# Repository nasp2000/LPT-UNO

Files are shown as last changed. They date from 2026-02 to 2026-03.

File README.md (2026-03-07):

# LPT-UNO — Parallel Port Printer Emulator


[]()
[]()
[]()

Turn an Arduino Uno into a **LPT/DB25 parallel port emulator**. Data received via the parallel interface is forwarded over USB Serial (or WiFi on R4) to a browser-based interface for real-time visualization and printing.

> No parallel printer required. Works with old DOS apps, legacy software, and educational setups.

<p align="center">
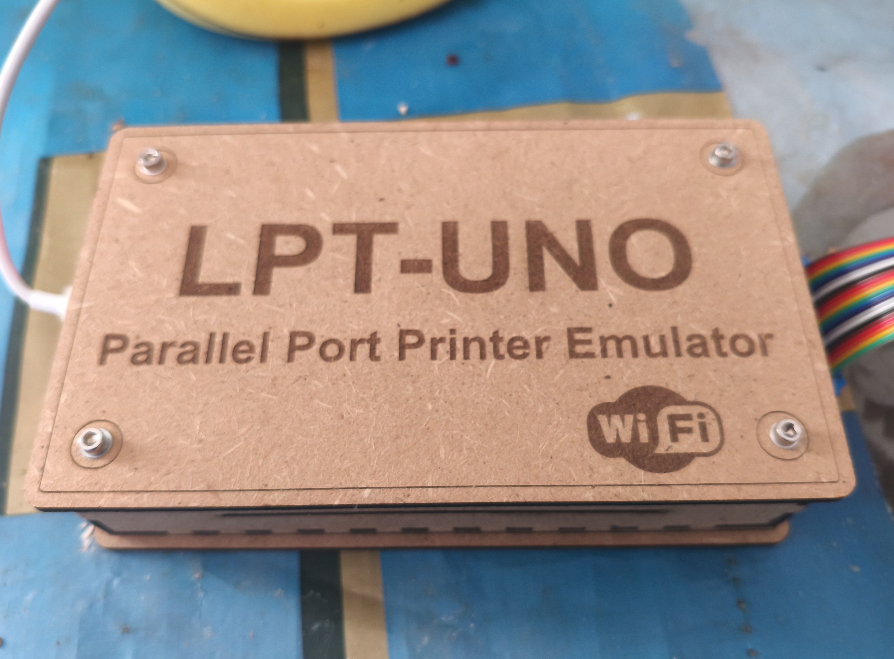
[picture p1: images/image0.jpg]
  
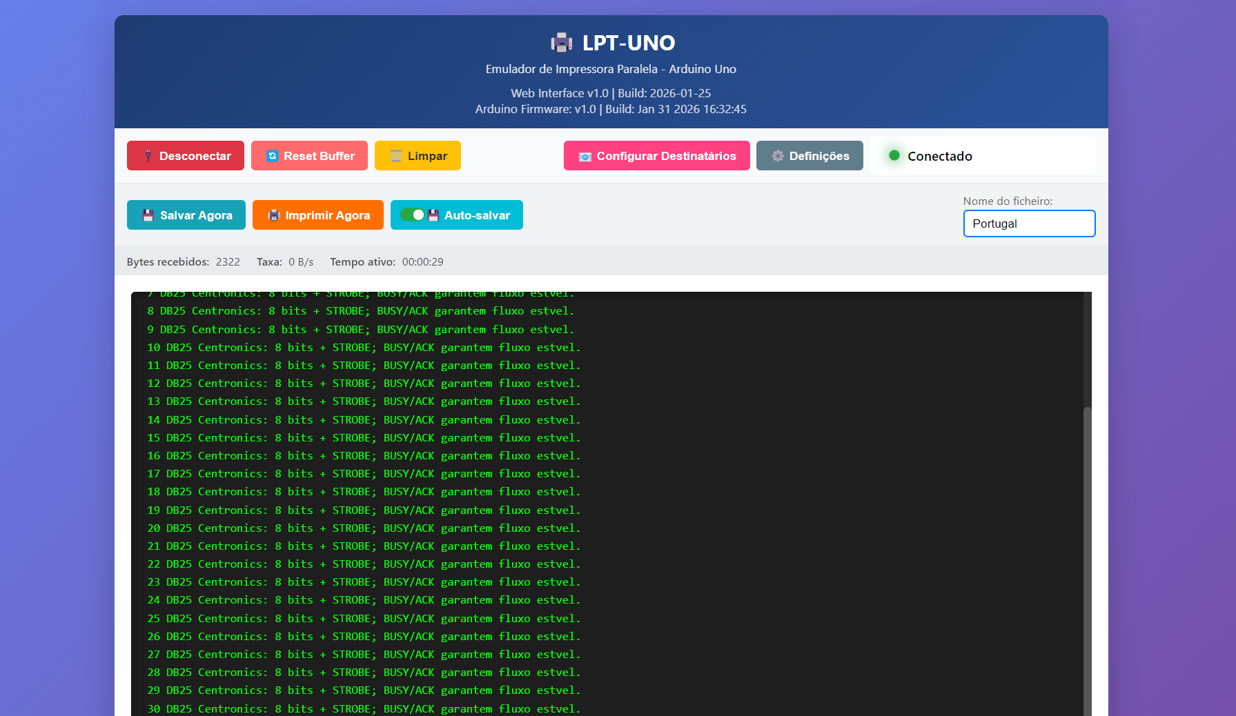
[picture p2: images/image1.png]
  
</p>
<p align="center">
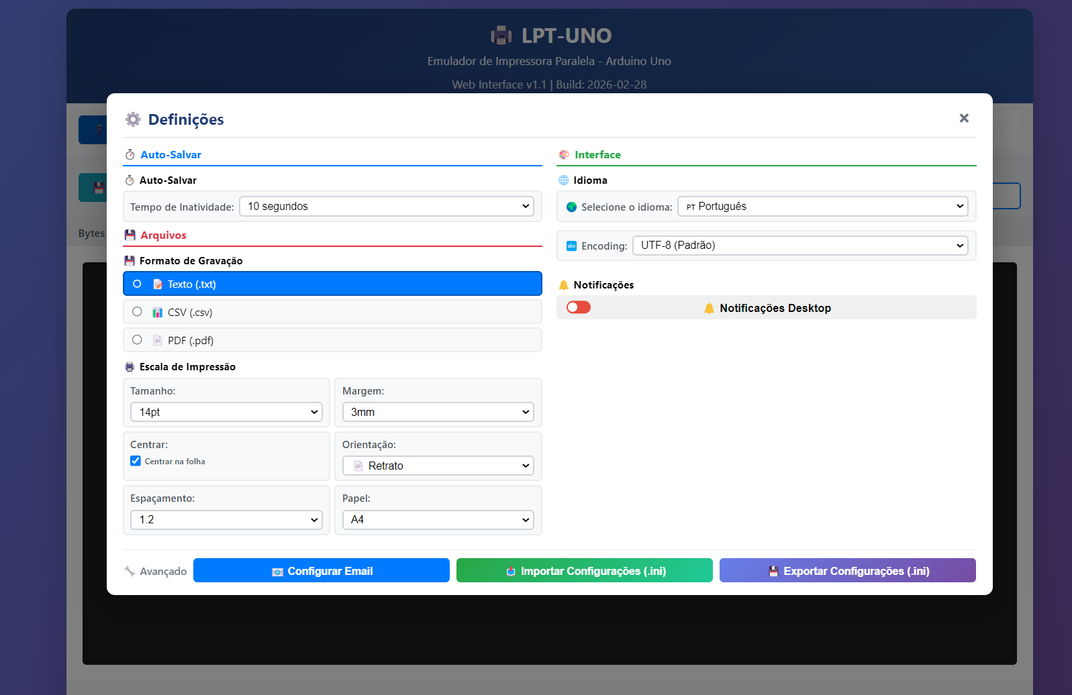
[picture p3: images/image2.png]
  
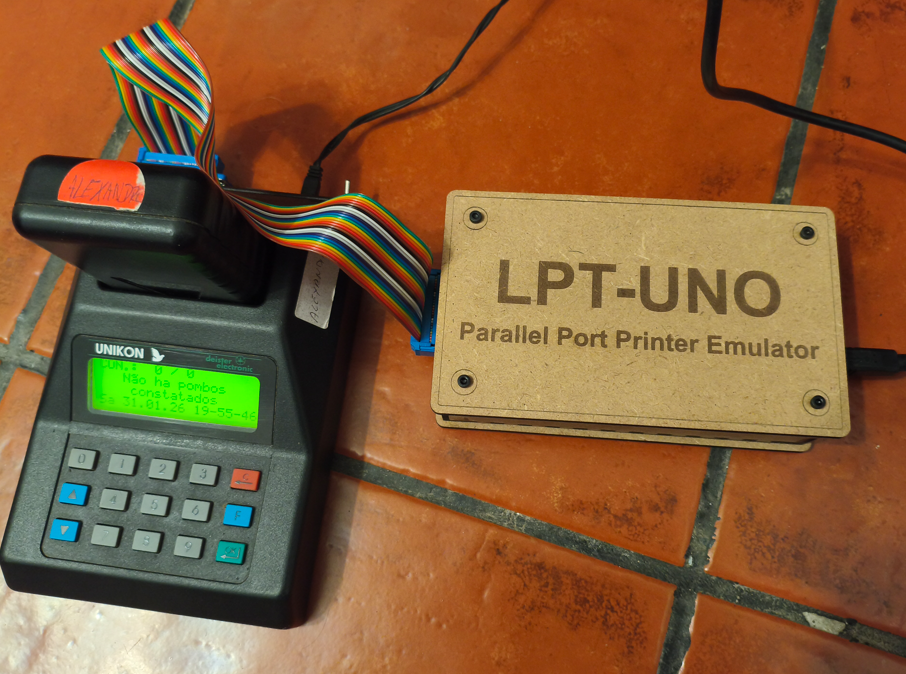
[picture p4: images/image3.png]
  
</p>

---

## Quick Start

1. Upload **LPT_Emulator/LPT_Emulator.ino** via Arduino IDE (115200 baud).
2. Open **web_interface.html** in Chrome or Edge.
3. Click **Connect** and select the Arduino COM port.

---

## Wiring (DB25 → Arduino)

| DB25 | Arduino | Signal |
|---|---|---|
| 1 | D2 | STROBE (INT0) |
| 2–9 | D3–D10 | D0–D7 (data) |
| 10 | D11 | ACK |
| 11 | D12 | BUSY |
| 13 | D13 | SELECT |
| 18–25 | GND | Ground |

> Use **5V TTL** levels only. See [PINOUT.txt](PINOUT.txt) for full diagram.

---

## Arduino Uno R4 WiFi

The R4 WiFi is fully supported with the same wiring. To use WiFi:

1. Upload the firmware to the Uno R4 WiFi.
2. Open **web_interface.html**, go to **Settings → WiFi** and enter your network credentials (SSID and password).
3. Click **Connect** — the interface discovers the board automatically or you can enter the IP manually.

| | Uno R3 | Uno R4 WiFi |
|---|---|---|
| CPU | ATmega328P 16 MHz | RA4M1 48 MHz |
| RAM | 2 KB | 32 KB |
| Connectivity | USB | USB + WiFi |

---

## Serial Commands

| Command | Action |
|---|---|
| `V` | Firmware version |
| `S` | Buffer usage |
| `R` | Reset buffer |
| `?` | Help |

---

## Troubleshooting

- **No connection:** check COM port, reset board, re-upload firmware.
- **No data:** verify STROBE is on pin D2, check wiring and GND.
- **Garbled text:** try CP‑437 encoding (DOS apps) in the web interface.
- **WiFi not found:** confirm credentials, check Serial Monitor for IP.

---

## License

MIT © 2026 LPT-UNO Project

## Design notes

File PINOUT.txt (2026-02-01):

╔════════════════════════════════════════════════════════════════╗
║      PINOUT - LPT PRINTER EMULATOR FOR ARDUINO UNO             ║
╚════════════════════════════════════════════════════════════════╝

┌─────────────────────────────────────────────────────────────────┐
│ DB25 CONNECTOR (FEMALE) - FRONT VIEW                           │
│                                                                 │
│     13  12  11  10   9   8   7   6   5   4   3   2   1        │
│    ○   ○   ○   ○   ○   ○   ○   ○   ○   ○   ○   ○   ○          │
│      ○   ○   ○   ○   ○   ○   ○   ○   ○   ○   ○   ○            │
│     25  24  23  22  21  20  19  18  17  16  15  14             │
└─────────────────────────────────────────────────────────────────┘

╔════════════════════════════════════════════════════════════════╗
║                    CONNECTION TABLE                            ║
╠════════╦═══════════╦═════════════╦═══════╦═════════════════════╣
║ DB25   ║  SIGNAL   ║  ARDUINO    ║ TYPE  ║  DESCRIPTION        ║
╠════════╬═══════════╬═════════════╬═══════╬═════════════════════╣
║   1    ║  STROBE   ║  Digital 2  ║  IN   ║ Data ready (INT0) ⚡║
║   2    ║  D0       ║  Digital 3  ║  IN   ║ Data bit 0          ║
║   3    ║  D1       ║  Digital 4  ║  IN   ║ Data bit 1          ║
║   4    ║  D2       ║  Digital 5  ║  IN   ║ Data bit 2          ║
║   5    ║  D3       ║  Digital 6  ║  IN   ║ Data bit 3          ║
║   6    ║  D4       ║  Digital 7  ║  IN   ║ Data bit 4          ║
║   7    ║  D5       ║  Digital 8  ║  IN   ║ Data bit 5          ║
║   8    ║  D6       ║  Digital 9  ║  IN   ║ Data bit 6          ║
║   9    ║  D7       ║  Digital 10 ║  IN   ║ Data bit 7          ║
║  10    ║  ACK      ║  Digital 11 ║  OUT  ║ Acknowledge         ║
║  11    ║  BUSY     ║  Digital 12 ║  OUT  ║ Busy                ║
║  12    ║  PAPER    ║  (not used) ║   -   ║ Paper out           ║
║  13    ║  SELECT   ║  Digital 13 ║  OUT  ║ Selected            ║
║  14    ║  AUTOFEED ║  (not used) ║   -   ║ Auto feed           ║
║  15    ║  ERROR    ║  (not used) ║   -   ║ Error               ║
║  16    ║  INIT     ║  (not used) ║   -   ║ Initialize          ║
║  17    ║  SELECT IN║  (not used) ║   -   ║ Select input        ║
║ 18-25  ║  GND      ║  GND        ║   -   ║ Ground              ║
╚════════╩═══════════╩═════════════╩═══════╩═════════════════════╝

╔════════════════════════════════════════════════════════════════╗
║                 ARDUINO WIRING DIAGRAM                         ║
╠════════════════════════════════════════════════════════════════╣
║                                                                ║
║   DB25 Pin 1  (STROBE) ──────────► Arduino D2  (INT0) ⚡       ║
║   DB25 Pin 2  (D0)     ──────────► Arduino D3                 ║
║   DB25 Pin 3  (D1)     ──────────► Arduino D4                 ║
║   DB25 Pin 4  (D2)     ──────────► Arduino D5                 ║
║   DB25 Pin 5  (D3)     ──────────► Arduino D6                 ║
║   DB25 Pin 6  (D4)     ──────────► Arduino D7                 ║
║   DB25 Pin 7  (D5)     ──────────► Arduino D8                 ║
║   DB25 Pin 8  (D6)     ──────────► Arduino D9                 ║
║   DB25 Pin 9  (D7)     ──────────► Arduino D10                ║
║   DB25 Pin 10 (ACK)    ◄────────── Arduino D11                ║
║   DB25 Pin 11 (BUSY)   ◄────────── Arduino D12                ║
║   DB25 Pin 13 (SELECT) ◄────────── Arduino D13 (LED)          ║
║   DB25 Pin 18-25 (GND) ──────────► Arduino GND                ║
║                                                                ║
║   Arduino USB ───────────────────► PC (Serial 115200 baud)    ║
╚════════════════════════════════════════════════════════════════╝

╔════════════════════════════════════════════════════════════════╗
║                  ⚠️  CRITICAL WARNING ⚠️                        ║
╠════════════════════════════════════════════════════════════════╣
║  STROBE MUST BE CONNECTED TO PIN 2 (INT0)!                    ║
║                                                                ║
║  Arduino Uno only has hardware interrupts on:                 ║
║  - Pin 2 (INT0)  ← Use this for STROBE                        ║
║  - Pin 3 (INT1)                                               ║
║                                                                ║
║  The emulator will NOT work if STROBE is on any other pin!    ║
╚════════════════════════════════════════════════════════════════╝

╔════════════════════════════════════════════════════════════════╗
║                    LOGIC LEVELS                                ║
╠════════════════════════════════════════════════════════════════╣
║  HIGH = 5V (logic 1)                                           ║
║  LOW  = 0V (logic 0)                                           ║
║                                                                ║
║  STROBE: Active LOW (low pulse indicates data ready)          ║
║  ACK:    Active LOW (low pulse = acknowledgment)              ║
║  BUSY:   Active HIGH (high level = busy)                      ║
║  SELECT: Active HIGH (high level = ready)                     ║
╚════════════════════════════════════════════════════════════════╝

╔════════════════════════════════════════════════════════════════╗
║                  PROTOCOL TIMING                               ║
╠════════════════════════════════════════════════════════════════╣
║                                                                ║
║  1. PC places data on D0-D7                                   ║
║  2. PC activates STROBE (HIGH → LOW)  ───┐                    ║
║  3. Arduino detects STROBE                │ < 2 µs (interrupt)║
║  4. Arduino activates BUSY (LOW → HIGH) ──┘                   ║
║  5. Arduino reads data                    ──┐                 ║
║  6. Arduino stores in buffer                │ ~10 µs          ║
║  7. Arduino sends ACK (LOW pulse)           │                 ║
║  8. Arduino deactivates BUSY (HIGH → LOW)───┘                 ║
║                                                                ║
║  ACK pulse width:   ~5 microseconds                           ║
║  BUSY time:         ~10 microseconds                          ║
║  Maximum rate:      ~100 kB/s (theoretical)                   ║
╚════════════════════════════════════════════════════════════════╝

╔════════════════════════════════════════════════════════════════╗
║                   IMPORTANT NOTES                              ║
╠════════════════════════════════════════════════════════════════╣
║                                                                ║
║  • Use short cables (< 2 meters) to avoid noise              ║
║  • Connect ALL GND pins (18-25) to Arduino GND               ║
║  • Arduino Uno uses 5V TTL levels (compatible with LPT)      ║
║  • Pin D2 has hardware interrupt (INT0) (essential for STROBE)  ║
║  • Pin D13 has onboard LED (useful for debugging)            ║
║  • Serial rate: 115200 baud (maximum speed)                  ║
║  • Buffer: 256 bytes circular                                 ║
║                                                                ║
╚════════════════════════════════════════════════════════════════╝

╔════════════════════════════════════════════════════════════════╗
║                  REQUIRED MATERIALS                            ║
╠════════════════════════════════════════════════════════════════╣
║                                                                ║
║  [ ] 1x Arduino Uno R3                                        ║
║  [ ] 1x DB25 female connector                                 ║
║  [ ] 1x USB cable type A-B                                    ║
║  [ ] 13x Jumper wires male-male (data + control)             ║
║  [ ] 1x Jumper wire for GND                                   ║
║  [ ] 1x Breadboard (optional, for organization)              ║
║  [ ] 1x Soldering iron + solder (if soldering DB25)          ║
║                                                                ║
╚════════════════════════════════════════════════════════════════╝

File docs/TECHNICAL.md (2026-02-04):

# Technical Reference — LPT-UNO

## Important Notes

- **STROBE must be on Arduino Pin 2 (INT0)**: Arduino Uno only has hardware interrupts on pins 2 and 3 (INT0/INT1). The STROBE signal MUST be connected to pin 2 (INT0) for the emulator to work.
- **Voltage levels**: Parallel ports use 5V TTL logic (Arduino Uno compatible).
- **Do NOT use** 3.3V Arduinos without proper level shifting.
- **Cable length**: Prefer cables < 2 meters to avoid noise and data corruption.
- **Ground connection**: Connect all DB25 ground pins (18-25) to Arduino GND.

---

## Software Installation

### Step 1: Upload Arduino Firmware

1. Download or clone this repository
2. Open `LPT_Emulator/LPT_Emulator.ino` in Arduino IDE
3. Tools → Board → Arduino Uno
4. Tools → Port → [Your COM Port]
5. Upload (Ctrl+U)

### Step 2: Test the Connection

Open Arduino Serial Monitor (115200 baud):
- `V` - show firmware version
- `S` - show statistics
- `R` - reset buffer
- `?` - help

### Step 3: Launch Native App

- Windows (recommended): build and run the `LPTUnoApp` application (see `LPTUnoApp/README.md`) to open the native interface and enable auto-print/move monitor.
- The legacy `web_interface.html` has been removed in this branch; use the native app for connection and printing.

---

## Web Interface Details

- **Encodings**: UTF-8 (default), ISO-8859-1 (Latin), CP-437 (DOS), Windows-1252. For CP-437 the UI uses a conversion table; other encodings use TextDecoder.
- **Auto-save**: configurable inactivity timer (default 10s).
- **Auto-print**: controlled by the native app (AutoPrint flag and Move Monitor). Files are moved from Downloads to `DATA` and printed by the app's `MoveManager` / `PrintManager` components (replacing `LPT-UNO_MoveToData.ps1`).

---

## Communication & Timing (IEEE 1284 compatibility)

1. PC places data on D0-D7 pins
2. PC toggles STROBE (HIGH → LOW transition)
3. Arduino detects STROBE via hardware interrupt
4. Arduino sets BUSY while processing
5. Arduino reads D0-D7 and stores the byte in a 256-byte circular buffer
6. Arduino pulses ACK (~5 μs low)
7. Arduino clears BUSY and forwards data via USB Serial in the main loop

**Timing specs:**
- STROBE detection: < 2 μs
- BUSY activation: ~10 μs
- ACK pulse: ~5 μs
- Max theoretical throughput: ~100 kB/s
- Serial baud rate: 115200

---

## Serial Commands

Type commands at 115200 baud in the Serial Monitor:

| Command | Action |
|---|---|
| `V` / `v` | Show firmware version and build date |
| `S` / `s` | Show statistics (buffer usage) |
| `R` / `r` | Reset buffer |
| `?` | Help |

Example:
```
> V
Firmware Version: 1.0
Build Date: Jan 25 2026 14:30:00

> S
Buffer usage: 42/256 bytes
```

---

## Pinout & Wiring

See `PINOUT.txt` for a complete ASCII diagram. Key mappings:
- STROBE: DB25 pin 1 → Arduino D2
- D0..D7: DB25 pins 2..9 → Arduino D3..D10
- ACK: DB25 pin 10 → Arduino D11
- BUSY: DB25 pin 11 → Arduino D12
- SELECT: DB25 pin 13 → Arduino D13
- GND: DB25 pins 18..25 → Arduino GND

---

## Debugging Tips

- If no data: confirm wiring and STROBE pin; test with Arduino Serial Monitor first.
- If characters are garbled: try CP-437 (DOS) or ISO-8859-1 in the UI; verify encoding of the source data.
- If auto-print doesn't run: ensure `.autoprint_enabled` exists in `DATA` and the native app's Move Monitor is running (see `LPTUnoApp` MoveManager).

---

(End of technical reference)

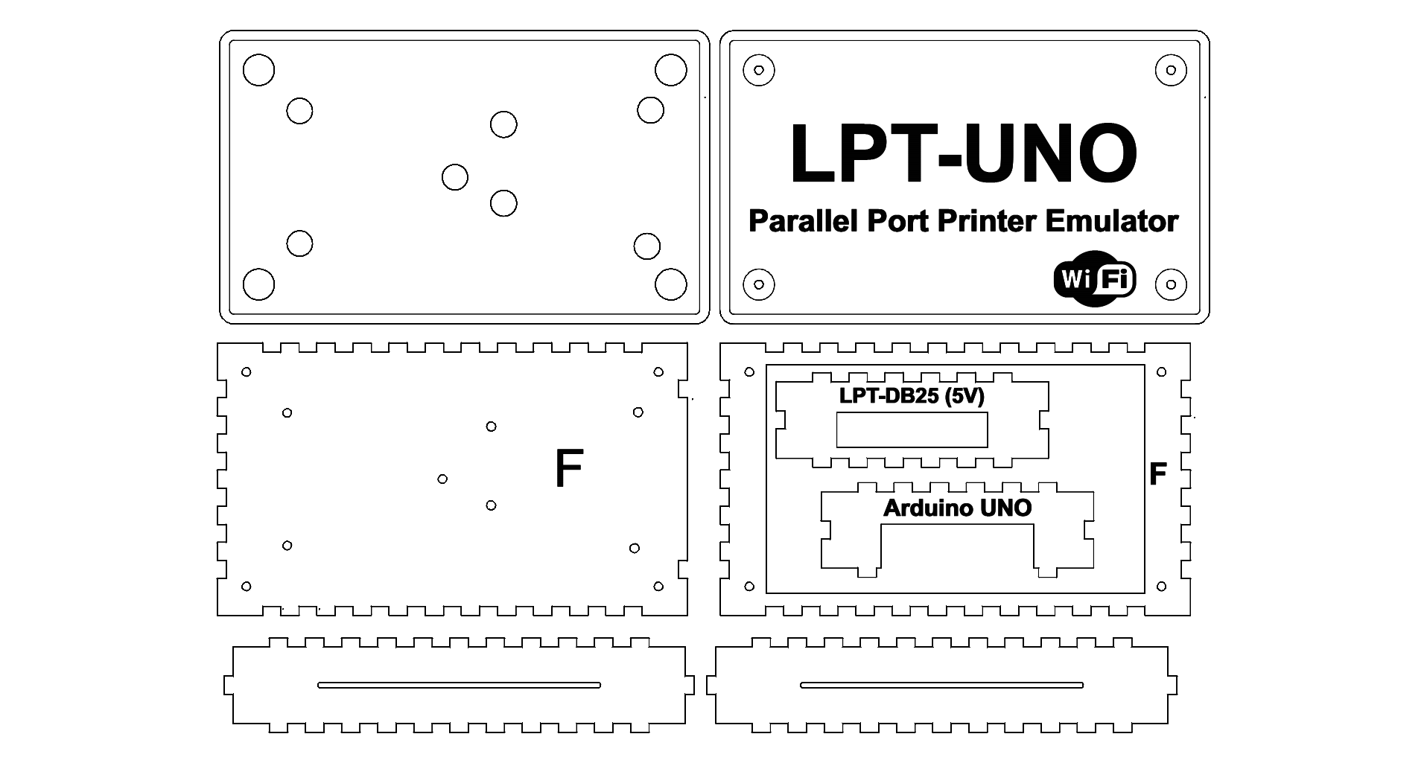
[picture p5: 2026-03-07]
images/drawings.png

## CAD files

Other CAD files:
images/drawings.dxf

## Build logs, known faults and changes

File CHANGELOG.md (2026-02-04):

# Changelog

All notable changes to the LPT-UNO project will be documented in this file.

The format is based on [Keep a Changelog](https://keepachangelog.com/en/1.0.0/),
and this project adheres to [Semantic Versioning](https://semver.org/spec/v2.0.0.html).

## [1.0] - 2026-01-31

### Added
- Initial release of LPT-UNO Parallel Port Printer Emulator
- Arduino Uno firmware with IEEE 1284 compatibility mode
- Web-based interface with Web Serial API support
- Auto-save feature (saves data every 10 seconds)
- Multi-language support (English, Portuguese, Spanish)
- Serial commands for monitoring and debugging (V, S, R, ?)
- 256-byte circular buffer for reliable data handling
- Hardware interrupt support for fast response (<2µs)
- Real-time data visualization in browser
- Manual save as TXT file
- Connection status indicators
- Firmware version display
- Buffer statistics monitoring
- **Controle de auto-print via Ativar_AutoPrint.bat e Desativar_AutoPrint.bat**
- **Automatic printing via LPT-UNO_MoveToData.ps1 (PowerShell)**
- **Launcher LPT-UNO_AutoPrint_Direct.bat para fluxo completo**

### Hardware
- Full pinout for DB25 to Arduino Uno
- Support for 8-bit parallel data (D0-D7)
- Control signals: STROBE, ACK, BUSY, SELECT
- Interrupt-driven STROBE detection on pin 2 (INT0)
- LED indicator on pin 13 (SELECT signal)

### Documentation
- Comprehensive README in English
- Detailed pinout diagram (PINOUT.txt)
- Wiring instructions and connection guide
- Troubleshooting section
- Technical specifications
- Development guidelines

### Files
- `LPT_Emulator/LPT_Emulator.ino` - Arduino firmware v1.0
- `LPTUnoApp/` - Native Windows app prototype (branch `LPT-UNO-Wifi`)
- `PINOUT.txt` - ASCII art pinout diagram
- `README.md` - Complete documentation
- `LICENSE` - MIT License
- `.gitignore` - Git ignore rules
- `.github/copilot-instructions.md` - Coding guidelines

---

## [Unreleased]

### Added
- Native Windows prototype app (WPF) in branch `LPT-UNO-Wifi` — initial prototype: tray app, config file, data folder and basic UI.
- AutoPrint watcher and PrintManager (monitor DATA folder and print `*.txt` files automatically). 
- Basic serial reconnection logic (periodic reconnection attempts to saved COM port).
- MoveToData functionality: monitor `Downloads` and move timestamped files into `DATA` (replaces `LPT-UNO_MoveToData.ps1`).
- Added controls to create/remove `.autoprint_enabled` flag and to start/stop Downloads monitor (replacing `Ativar/Desativar_AutoPrint.bat` behaviors).
- Added installer packaging scripts and an Inno Setup definition for Windows installer (`installer/`).

### Removed
- `web_interface.html` — Legacy web interface removed in favor of the native app (branch `LPT-UNO-Wifi`).
- Legacy helper scripts removed: `Ativar_AutoPrint.bat`, `Desativar_AutoPrint.bat`, `LPT-UNO_AutoPrint_Direct.bat`, `LPT-UNO_MoveToData.ps1` (functionality replaced by MoveManager/PrintManager).

### Fixed
- Discovery: Handle IPv6 addresses and bracketed `[IPv6]:port` notation to allow auto-connect on IPv6 networks.
- Tray icon: Properly destroy native icon handle on exit to avoid resource leak.

### Added
- Minimize-to-tray preference (persisted in config) with UI checkbox `ChkMinimizeToTray`.
- Runtime creation of a placeholder `images/printer.png` when missing and automatic generation of `TrayIcon.ico` so the app always shows a tray icon.
- Programmatically generate a simple printer icon (32×32) when no custom icon is supplied.

### Future Ideas
- Support for other Arduino boards (Mega, Due, ESP32)
- Bidirectional communication (EPP/ECP modes)
- Mobile-friendly responsive interface
- Linux/macOS launcher scripts
- Advanced printer emulation features
- Configuration file support
- Data filtering and formatting options
- Multiple buffer size options
- Advanced timing adjustment
- Built-in data logger
- Network printing support
- Virtual printer driver

---

## Version Numbering

- **Major (X.0.0)**: Breaking changes, major new features, architectural changes
- **Minor (1.X.0)**: New features, improvements, significant bug fixes
- **Patch (1.0.X)**: Small bug fixes, documentation updates (optional)

---

*For a complete list of changes, see the [commit history](https://github.com/yourusername/LPT-UNO/commits).*

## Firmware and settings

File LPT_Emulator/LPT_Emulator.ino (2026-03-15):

/*
 * Emulador de Impressora Paralela LPT (DB25) para Arduino Uno
 * LPT-UNO Firmware
 * 
 * Este código transforma o Arduino Uno num emulador de impressora paralela
 * que recebe dados pela interface paralela e os envia via USB Serial para o PC.
 * 
 * PINAGEM DO ARDUINO UNO:
 * ========================
 * Sinais de Controle:
 *   STROBE (DB25 pino 1)   -> Arduino Digital 2 (INT0 - Interrupt)
 *   ACK    (DB25 pino 10)  -> Arduino Digital 11 (Output)
 *   BUSY   (DB25 pino 11)  -> Arduino Digital 12 (Output)
 *   SELECT (DB25 pino 13)  -> Arduino Digital 13 (Output + LED)
 * 
 * Dados Paralelos (8 bits):
 *   D0 (DB25 pino 2)  -> Arduino Digital 3
 *   D1 (DB25 pino 3)  -> Arduino Digital 4
 *   D2 (DB25 pino 4)  -> Arduino Digital 5
 *   D3 (DB25 pino 5)  -> Arduino Digital 6
 *   D4 (DB25 pino 6)  -> Arduino Digital 7
 *   D5 (DB25 pino 7)  -> Arduino Digital 8
 *   D6 (DB25 pino 8)  -> Arduino Digital 9
 *   D7 (DB25 pino 9)  -> Arduino Digital 10
 * 
 * GND: DB25 pinos 18-25 -> Arduino GND
 * 
 * PROTOCOLO:
 * 1. PC coloca dados nos pinos D0-D7
 * 2. PC ativa STROBE (nível baixo)
 * 3. Arduino lê os dados
 * 4. Arduino ativa BUSY (nível alto)
 * 5. Arduino processa/envia dados via USB Serial
 * 6. Arduino ativa ACK (pulso baixo)
 * 7. Arduino desativa BUSY (nível baixo)
 */

// ===========================
// INFORMAÇÕES DE VERSÃO
// ===========================
#define FIRMWARE_VERSION "1.1"
#define BUILD_DATE __DATE__
#define BUILD_TIME __TIME__

// ===========================
// WIFI SUPPORT (UNO R4 WIFI)
// ===========================
#if defined(ARDUINO_UNOR4_WIFI)
#include "WiFiS3.h"
#include <EEPROM.h>
#include <WiFiUdp.h>
#include <ArduinoMDNS.h>

// Credentials storage
struct Config {
  char ssid[33];
  char pass[64];
  byte valid;  // 0xAA indicates valid config
} wifiConfig;

int status = WL_IDLE_STATUS;
bool wifiConnected = false;

// HTTP server para web interface via streaming bruto (porta 80)
WiFiServer webServer(80);
WiFiClient streamClient;
bool streamClientConnected = false;

// Discovery
WiFiUDP udp;
unsigned long lastBroadcast = 0;

// mDNS — acessível como lpt-uno.local
WiFiUDP mdnsUdp;
MDNS mdns(mdnsUdp);

// Reconexão automática WiFi (state machine não-bloqueante)
unsigned long lastWifiCheck    = 0;
bool          wifiAttempting   = false;
unsigned long wifiAttemptStart = 0;
const unsigned long WIFI_CONNECT_ATTEMPT_TIMEOUT_MS = 12000UL;
const unsigned long WIFI_RETRY_INTERVAL_MS          = 3000UL;
bool          _wifiServicesStarted = false;   // impede webServer/udp.begin() repetido
unsigned long _lastKeepaliveMs     = 0;       // keepalive TCP no stream (0x00 a cada 5s)
#endif

// Buffer de receção de comandos Serial (não-bloqueante)
String serialCmdBuffer = "";

#if defined(ARDUINO_UNOR4_WIFI)
void loadConfig() {
  EEPROM.get(0, wifiConfig);
}

void saveConfig(String s, String p) {
  memset(wifiConfig.ssid, 0, 33);
  memset(wifiConfig.pass, 0, 64);
  s.toCharArray(wifiConfig.ssid, 33);
  p.toCharArray(wifiConfig.pass, 64);
  wifiConfig.valid = 0xAA;
  EEPROM.put(0, wifiConfig);
}

void startWifiConnectAttempt() {
  WiFi.disconnect();
  delay(60);
  WiFi.begin(wifiConfig.ssid, wifiConfig.pass);
  wifiAttempting   = true;
  wifiAttemptStart = millis();
}

// Buffer de stream HTTP bruto — sem overhead SSE/texto.
// O browser lê bytes raw com fetch().body.getReader(), o que é muito mais leve.
#define STREAM_BUF_CAP 2048
#define STREAM_FLUSH_THRESHOLD ((STREAM_BUF_CAP * 3) / 4)  // flush preventivo a ~75%
static uint8_t _streamBuf[STREAM_BUF_CAP];
static int     _streamBufLen = 0;
unsigned long  lastStreamFlush = 0;

void sendStreamData(byte b) {
  if (!streamClientConnected || !streamClient.connected()) {
    streamClientConnected = false;
    _streamBufLen = 0;
    return;
  }
  if (_streamBufLen >= STREAM_BUF_CAP - 1) flushStream();
  if (_streamBufLen < STREAM_BUF_CAP) {
    _streamBuf[_streamBufLen++] = b;
  }
  if (_streamBufLen >= STREAM_FLUSH_THRESHOLD) flushStream();
}

void flushStream() {
  if (_streamBufLen == 0 || !streamClientConnected || !streamClient.connected()) {
    if (_streamBufLen > 0) _streamBufLen = 0;
    return;
  }
  streamClient.write(_streamBuf, _streamBufLen);
  _streamBufLen = 0;
  lastStreamFlush = millis();
}

// ── Estado do cliente HTTP pendente ─────────────────────────────────────────
// O request é acumulado ao longo de várias iterações do loop (não-bloqueante).
// Resolve o problema anterior: timeout de 5µs/5ms era insuficiente para o
// WiFiS3 entregar os headers completos → GET /events nunca era reconhecido
// → EventSource fechava imediatamente → ciclo de retry infinito.
WiFiClient    _httpClient;
String        _httpReq     = "";
unsigned long _httpReqT    = 0;
bool          _httpPending = false;

bool _httpHasRequestLine(const String& req) {
  return req.indexOf("\r\n") >= 0 || req.indexOf('\n') >= 0;
}

bool _httpIsRecognizedPath(const String& req) {
  return req.indexOf("GET /ping") >= 0
      || req.indexOf("GET /stream") >= 0
      || req.indexOf("GET /status") >= 0
      || req.indexOf("GET /ip") >= 0;
}

// Despacha o request HTTP completo (ou com timeout)
void _dispatchHttp(WiFiClient& c, const String& req) {
  if (req.indexOf("GET /ping") >= 0) {
    c.println("HTTP/1.1 200 OK");
    c.println("Content-Type: application/json");
    c.println("Access-Control-Allow-Origin: *");
    c.println("Connection: close");
    c.println();
    IPAddress ip = WiFi.localIP();
    c.print("{\"d\":\"LPT-UNO\",\"ip\":\"");
    c.print(ip);
    c.print("\"}");
    c.stop();
  } else if (req.indexOf("GET /stream") >= 0) {
    c.println("HTTP/1.1 200 OK");
    c.println("Content-Type: application/octet-stream");
    c.println("Cache-Control: no-cache");
    c.println("Access-Control-Allow-Origin: *");
    c.println("Connection: keep-alive");
    c.println();
    c.flush();  // forçar envio imediato dos headers ao browser
    if (streamClient && streamClient.connected()) streamClient.stop();
    streamClient = c;
    streamClientConnected = true;
  } else if (req.indexOf("GET /status") >= 0 || req.indexOf("GET /ip") >= 0) {
    IPAddress ip = WiFi.localIP();
    String s = "{\"version\":\"" + String(FIRMWARE_VERSION) + "\",\"ip\":\""
               + String(ip[0])+"."+String(ip[1])+"."+String(ip[2])+"."+String(ip[3]) + "\"}";
    c.println("HTTP/1.1 200 OK");
    c.println("Content-Type: application/json");
    c.println("Access-Control-Allow-Origin: *");
    c.println("Connection: close");
    c.println();
    c.print(s);
    c.stop();
  } else {
    c.println("HTTP/1.1 200 OK");
    c.println("Content-Type: text/plain");
    c.println("Access-Control-Allow-Origin: *");
    c.println("Connection: close");
    c.println();
    IPAddress ip = WiFi.localIP();
    c.print("LPT-UNO v"); c.println(FIRMWARE_VERSION);
    c.print("STREAM: http://"); c.print(ip); c.println("/stream");
    c.stop();
  }
}

// Trata ligações HTTP — completamente não-bloqueante.
// IMPORTANTE: não aceita novas ligações enquanto stream activo — o WiFiS3
// devolve o próprio socket stream em webServer.available(), o que levaria
// o código a tratá-lo como novo pedido e após 500ms chamar c.stop(),
// matando a ligação HTTP streaming.
void handleWebClient() {
  // Enquanto stream activo e saudável: não aceitar novas ligações
  if (streamClientConnected) {
    if (!streamClient.connected()) {
      streamClientConnected = false;
      _streamBufLen = 0;
      _httpPending = false;
    }
    return;
  }

  // Aceitar novo cliente apenas se não há pedido em curso
  if (!_httpPending) {
    WiFiClient nc = webServer.available();
    if (!nc) return;
    _httpClient  = nc;
    _httpReq     = "";
    _httpReqT    = millis();
    _httpPending = true;
  }

  // Ler apenas o que já está no buffer (nunca esperar)
  while (_httpPending && _httpClient.connected()
         && _httpClient.available() && _httpReq.length() < 1024) {
    _httpReq += (char)_httpClient.read();
    if (_httpReq.endsWith("\r\n\r\n") || (_httpHasRequestLine(_httpReq) && _httpIsRecognizedPath(_httpReq))) {
      _httpPending = false;
      _dispatchHttp(_httpClient, _httpReq);
      return;
    }
  }

  // Timeout 500ms ou cliente desligou: despachar com o que foi recebido
  if (_httpPending && (!_httpClient.connected() || millis() - _httpReqT > 500UL)) {
    _httpPending = false;
    _dispatchHttp(_httpClient, _httpReq);
  }
}
#endif

// ===========================
// DEFINIÇÃO DE PINOS
// ===========================

// Pinos de controle (Input do PC)
const int PIN_STROBE = 2;  // Sinal de dados prontos (active low) - INT0

// Pinos de dados (D0-D7)
const int DATA_PINS[] = { 3, 4, 5, 6, 7, 8, 9, 10 };
const int DATA_PIN_COUNT = 8;

// Pinos de status (Output para o PC)
const int PIN_ACK = 11;     // Acknowledge (active low pulse)
const int PIN_BUSY = 12;    // Impressora ocupada (active high)
const int PIN_SELECT = 13;  // Impressora selecionada (active high)

// ===========================
// CONFIGURAÇÃO DE TIMING
// ===========================
// ACK mínimo IEEE 1284 = 0.5µs; 2µs é suficiente e seguro
// BUSY_DELAY = tempo de processamento simulado antes do ACK
// Ambos reduzidos para 2µs: ISR total ~4-6µs → suporta até HIPER_RAPIDO (gap=10µs)
// Profile de velocidades (teste):
//   LENTO:        dataSettle=10µs  strobe=50µs  gap=200µs  ✓
//   NORMAL:       dataSettle= 5µs  strobe=20µs  gap=100µs  ✓
//   RAPIDO:       dataSettle= 2µs  strobe= 8µs  gap= 30µs  ✓
//   SUPER_RAPIDO: dataSettle= 1µs  strobe= 5µs  gap= 15µs  ✓
//   HIPER_RAPIDO: dataSettle= 1µs  strobe= 3µs  gap= 10µs  ✓
const unsigned long ACK_PULSE_MICROS = 2;    // Pulso ACK: 2µs (mínimo seguro)
const unsigned long BUSY_DELAY_MICROS = 2;   // Processamento: 2µs

// ===========================
// BUFFER DE DADOS
// ===========================
#if defined(ARDUINO_UNOR4_WIFI)
const int BUFFER_SIZE = 8192;   // R4 WiFi: margem real para bursts longos via SSE/WiFi
const int DRAIN_BATCH_SIZE = 384;
const int BUFFER_BUSY_HIGH_WATER = (BUFFER_SIZE * 3) / 4;  // 75%
const int BUFFER_BUSY_LOW_WATER  = BUFFER_SIZE / 2;        // 50% (histerese)
#else
const int BUFFER_SIZE = 256;
const int DRAIN_BATCH_SIZE = 32;
const int BUFFER_BUSY_HIGH_WATER = BUFFER_SIZE / 2;        // 50%
const int BUFFER_BUSY_LOW_WATER  = BUFFER_SIZE / 4;        // 25% (histerese)
#endif
volatile byte dataBuffer[BUFFER_SIZE];
volatile int bufferWriteIndex = 0;
volatile int bufferReadIndex = 0;
volatile bool dataAvailable = false;
volatile unsigned long bufferOverflowCount = 0;
volatile bool flowControlBusy = false;

// ===========================
// VARIÁVEIS DE ESTADO
// ===========================
volatile unsigned long lastStrobeTime = 0;
const unsigned long DEBOUNCE_MICROS = 2;   // Debounce de 2µs
volatile unsigned long strobeCounter = 0;  // Contador de interrupções (debug)

// ===========================
// SETUP
// ===========================
void setup() {
  // Inicializar comunicação serial USB (velocidade alta)
  Serial.begin(115200);
  // Aguardar Serial até 3s — permite arrancar sem PC ligado via USB
  { unsigned long _t = millis(); while (!Serial && (millis() - _t) < 3000) {} }

  // Configurar pinos de dados como INPUT
  for (int i = 0; i < DATA_PIN_COUNT; i++) {
    pinMode(DATA_PINS[i], INPUT);
  }

  // Configurar pinos de controle
  pinMode(PIN_STROBE, INPUT_PULLUP);  // STROBE é active low

  // Configurar pinos de status como OUTPUT
  pinMode(PIN_ACK, OUTPUT);
  pinMode(PIN_BUSY, OUTPUT);
  pinMode(PIN_SELECT, OUTPUT);

  // Estado inicial dos sinais
  digitalWrite(PIN_ACK, HIGH);     // ACK em repouso (high)
  digitalWrite(PIN_BUSY, LOW);     // Não ocupado
  digitalWrite(PIN_SELECT, HIGH);  // Selecionado e pronto

  // Configurar interrupção no pino STROBE (falling edge)
  attachInterrupt(digitalPinToInterrupt(PIN_STROBE), handleStrobe, FALLING);

  // Mensagem de inicialização
  Serial.println("===================================");
  Serial.println("LPT-UNO Emulator");
  Serial.print("Firmware: v");
  Serial.println(FIRMWARE_VERSION);
  Serial.print("Build: ");
  Serial.print(BUILD_DATE);
  Serial.print(" ");
  Serial.println(BUILD_TIME);
  Serial.println("===================================");
  Serial.println("Ready - Waiting for parallel data...");

#if defined(ARDUINO_UNOR4_WIFI)
  // Inicialização do WiFi (apenas R4 WiFi)
  if (WiFi.status() == WL_NO_MODULE) {
    Serial.println("Communication with WiFi module failed!");
  } else {
    // Firmware check disabled by default to avoid spurious messages for users.
    // To enable and require a minimum WiFi firmware version, define
    // WIFI_FIRMWARE_LATEST_VERSION and set WIFI_FIRMWARE_CHECK to 1 at the top
    // of this file. Example:
    //   #define WIFI_FIRMWARE_CHECK 1
    //   #define WIFI_FIRMWARE_LATEST_VERSION "1.0.0"
    // Then uncomment the lines below.
    // String fv = WiFi.firmwareVersion();
    // if (fv < WIFI_FIRMWARE_LATEST_VERSION) {
    //   Serial.println("Please upgrade the firmware");
    // }

    // Load credentials
    loadConfig();

    if (wifiConfig.valid == 0xAA) {
      Serial.print("Connecting to SSID: ");
      Serial.println(wifiConfig.ssid);

      // Ligar ao WiFi — polling não-bloqueante (máx. 12s)
      // ⚠️ Drena o buffer durante a espera para não perder dados paralelos recebidos
      //    neste periodo (a ISR está activa mas o loop() ainda não iniciou)
      startWifiConnectAttempt();
      {
        unsigned long _wStart = millis();
        while (WiFi.status() != WL_CONNECTED && (millis() - _wStart) < WIFI_CONNECT_ATTEMPT_TIMEOUT_MS) {
          delay(200);
          // Esvaziar buffer circular durante a espera
          while (bufferReadIndex != bufferWriteIndex) {
            Serial.write(dataBuffer[bufferReadIndex]);
            bufferReadIndex = (bufferReadIndex + 1) % BUFFER_SIZE;
          }
        }
      }
      status = WiFi.status();

      if (status == WL_CONNECTED) {
        wifiConnected = true;
        webServer.begin();  // HTTP streaming para web interface (porta 80)
        udp.begin(2324);    // Start UDP on port 2324
        mdns.begin(WiFi.localIP(), "lpt-uno");  // mDNS: lpt-uno.local
        _wifiServicesStarted = true;  // marcar para evitar begin() duplo no loop
        printWifiStatus();
      } else {
        Serial.println("WiFi: falha na ligacao inicial. Auto-reconecta em background.");
        // Iniciar contagem de reconexão a partir de agora (não de millis()=0)
        // para que a primeira retentativa ocorra em 10s e não em 10s+boot
        lastWifiCheck = millis();
      }
    } else {
      Serial.println("No WiFi config. Use: CMD:WIFI:SSID:PASS");
    }
  }
#endif
}

// ===========================
// LOOP PRINCIPAL
// ===========================
void loop() {
#if defined(ARDUINO_UNOR4_WIFI)
  {
    unsigned long _now = millis();

    // ── Throttle: tarefas WiFi no máximo 1× por 2ms ───────────────────
    // Sem este guard, o WiFi consome CPU em cada iteração do loop e
    // atrasa o caminho crítico de dados (buffer → Serial.write)
    static unsigned long _lastWifiMs = 0;
    if (_now - _lastWifiMs >= 2UL) {
      _lastWifiMs = _now;

      // ── Detectar queda de ligação ──────────────────────────────────────
      if (wifiConnected && WiFi.status() != WL_CONNECTED) {
        wifiConnected      = false;
        streamClientConnected = false;
        wifiAttempting     = false;
        WiFi.disconnect();
        lastWifiCheck      = _now;
      }

      // ── Iniciar tentativa de reconexão (cada 10s) ──────────────────────
      if (wifiConfig.valid == 0xAA && !wifiConnected && !wifiAttempting
          && (_now - lastWifiCheck > WIFI_RETRY_INTERVAL_MS)) {
        startWifiConnectAttempt();
      }

      // ── Verificar resultado da tentativa ──────────────────────────────
      if (wifiAttempting) {
        if (WiFi.status() == WL_CONNECTED) {
          wifiConnected  = true;
          wifiAttempting = false;
          // webServer e udp são iniciados apenas uma vez (sockets sobrevivem ao reconnect WiFi)
          if (!_wifiServicesStarted) {
            webServer.begin();
            udp.begin(2324);
            _wifiServicesStarted = true;
          }
          mdns.begin(WiFi.localIP(), "lpt-uno");  // re-announce mDNS no novo IP
          printWifiStatus();
        } else if (_now - wifiAttemptStart > WIFI_CONNECT_ATTEMPT_TIMEOUT_MS) {
          wifiAttempting = false;
          lastWifiCheck  = _now;
        }
      }

      // ── Serviços quando ligado ─────────────────────────────────────────
      if (wifiConnected) {
        // UDP Discovery Broadcast every 2 seconds
        if (_now - lastBroadcast > 2000) {
          lastBroadcast = _now;
          udp.beginPacket(IPAddress(255, 255, 255, 255), 2324);
          udp.write("LPT-UNO-R4");
          udp.endPacket();
        }
        
        // Verificar saúde do stream a cada iteração (cada 2ms)
        // e handleWebClient() recusa novas ligações para sempre
        if (streamClientConnected && !streamClient.connected()) {
          streamClientConnected = false;
          _streamBufLen = 0;
        }

        // Flush stream só quando vale a pena: buffer grande ou janela curta.
        if (_streamBufLen >= 768 || (_streamBufLen > 0 && (_now - lastStreamFlush > 8))) {
          flushStream();
        }

        // ── Keepalive TCP: envia 0x00 a cada 5s quando stream activo e sem dados ───
        // Evita que o router/WiFiS3 feche o socket TCP por idle e que o browser
        // fique preso num read() infinito sem receber FIN.
        // O browser filtra 0x00 (não aparece no output nem nos dados capturados).
        if (streamClientConnected && (_now - _lastKeepaliveMs > 5000UL)) {
          _lastKeepaliveMs = _now;
          // Envio directo (fora do buffer) para garantir entrega imediata
          if (streamClient.connected()) {
            streamClient.write((uint8_t)0x00);
            streamClient.flush();
          }
        }

        // mDNS e HTTP — não-bloqueantes
        mdns.run();
        handleWebClient();
      }
    } // fim throttle 2ms
  }
#endif

  // Check for Serial Commands (Config) - não-bloqueante (char a char)
  // Guardar com Serial: sem USB ligado, Serial.available() é sempre 0 mas
  // chamar em loop desnecessário gasta ciclos — a guarda é gratuita
  while (Serial && Serial.available() > 0) {
    char c = (char)Serial.read();
    if (c == '\n' || c == '\r') {
      // Linha completa recebida
      serialCmdBuffer.trim();
      if (serialCmdBuffer.length() > 0) {
        String input = serialCmdBuffer;
        serialCmdBuffer = "";  // limpar buffer
        // Legacy single char commands
        if (input.length() == 1) {
          switch (input[0]) {
            case 'R':
            case 'r':
              resetBuffer();
              Serial.println("Buffer reset");
              break;
            case 'S':
            case 's': printStats(); break;
            case 'V':
            case 'v': printVersion(); break;
            case 'I':
            case 'i': printIdentification(); break;
          }
        }
#if defined(ARDUINO_UNOR4_WIFI)
        // CMD:WIFI:SSID:PASS
        else if (input.startsWith("CMD:WIFI:")) {
          // Remover prefixo "CMD:WIFI:"
          String rest = input.substring(9);  // tudo depois de "CMD:WIFI:"
          int colonPos = rest.indexOf(':');
          if (colonPos > 0) {
            String newSSID = rest.substring(0, colonPos);
            String newPass = rest.substring(colonPos + 1);
            newSSID.trim();
            newPass.trim();
            Serial.print("OK:WIFI:SAVING:");
            Serial.println(newSSID);
            saveConfig(newSSID, newPass);
            Serial.println("OK:WIFI:SAVED");
            delay(200);
            Serial.println("OK:RESTARTING");
            delay(200);
            NVIC_SystemReset();
          } else {
            Serial.println("ERR:WIFI:FORMAT");
          }
        }
#endif
      } else {
        serialCmdBuffer = "";  // descartar linha vazia
      }
    } else {
      // Acumular caracteres no buffer (ignorar overflow)
      if (serialCmdBuffer.length() < 128) {
        serialCmdBuffer += c;
      }
    }
  }

  // Drenar buffer circular em batches maiores no R4 WiFi.
  {
    int _cnt = 0;
    while (bufferReadIndex != bufferWriteIndex && _cnt < DRAIN_BATCH_SIZE) {
      byte b = dataBuffer[bufferReadIndex];
      bufferReadIndex = (bufferReadIndex + 1) % BUFFER_SIZE;
      if (Serial) Serial.write(b);
#if defined(ARDUINO_UNOR4_WIFI)
      if (wifiConnected && streamClientConnected) sendStreamData(b);
#endif
      _cnt++;
    }
  }

  // Libertar BUSY apenas quando o buffer já saiu da zona de risco.
  // Isto introduz backpressure real no protocolo Centronics e evita bursts
  // acima da capacidade instantânea do caminho WiFi/browser.
  if (flowControlBusy) {
    noInterrupts();
    int bufferUsed = (bufferWriteIndex - bufferReadIndex + BUFFER_SIZE) % BUFFER_SIZE;
    if (bufferUsed <= BUFFER_BUSY_LOW_WATER) {
      flowControlBusy = false;
      interrupts();
      digitalWrite(PIN_BUSY, LOW);
    } else {
      interrupts();
    }
  }
      // Flush stream feito no bloco WiFi (2ms) — não aqui

}
// fim loop()
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

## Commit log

2026-01-31 Add LPT-UNO Auto-Print Mode Launcher and upload checklist documentation
    - Created LPT-UNO_AutoPrint.bat for launching the web interface with auto-print enabled.
    - Added UPLOAD-CHECKLIST.md to ensure all necessary files and documentation are prepared for GitHub upload.
2026-02-01 feat: Add LPT-UNO Auto-Print and Download Monitor Scripts
    - Created LPT-UNO_AutoPrint_Direct.bat for automatic printing of downloaded files.
    - Implemented LPT-UNO_MoveToData.ps1 to monitor Downloads folder and move files to DATA directory.
    - Added SVG images for LPT-UNO interface (image1.svg, image2.svg, image3.svg, image4.svg).
2026-02-01 fix: Update changelog and documentation for clarity and consistency in auto-print features
2026-02-01 feat: enhance auto-print functionality with status messages and user guidance
2026-02-03 Add native WPF app prototype (LPT-UNO-Wifi): tray, config, README
2026-02-03 Add PrintManager: auto-print watcher, printer UI; add serial reconnection timer; update README and CHANGELOG
2026-02-28 feat: WiFi v1.1 - SSE connectivity, auto-discovery and UI improvements
    - Firmware: HTTP/SSE server for wireless data transmission (port 80)
    - WiFi credentials via Serial command (CMD:WIFI:SSID:PASS)
    - Web interface: WiFi modal with configuration and SSE connectivity
    - Auto-discovery via subnet scan (mDNS removed - not available on R4)
    - Centralized WiFi modal buttons
    - Auto-print system with batch files for Windows integration
    - Bug fixes: savedPrefs declaration, Serial error suppression
    - Removed mDNS dependencies (WiFiMDNS.h not available for Arduino R4 WiFi)
    [LPT_Emulator.ino]
2026-03-07 chore: clean up empty code change sections in the changes log
    [drawings.dxf]
2026-03-14 feat: add print copies selection and enhance printing functionality
2026-03-15 feat: Enhance WiFi connection handling and add Form Feed processing option
    - Refactored WiFi connection logic to use non-blocking attempts with configurable timeouts and retry intervals.
    - Introduced a keepalive mechanism to prevent TCP socket closure during idle periods.
    - Added a new Form Feed option in the web interface to process print jobs immediately upon receiving a Form Feed command.
    - Implemented a PowerShell script for printing that reads configuration from a sidecar JSON file, allowing for customizable print settings.
    - Updated HTML and JavaScript to support new features, including silent printing mode and immediate Form Feed processing.
    [LPT_Emulator.ino]
2026-03-15 feat: streamline file processing and enhance print configuration handling
2026-03-15 feat: implement separate print configuration file handling and update related logic
2026-03-19 feat: enhance print rendering quality and implement email data deduplication
2026-03-20 feat: implement daily subfolder organization for files and enhance print configuration restoration
